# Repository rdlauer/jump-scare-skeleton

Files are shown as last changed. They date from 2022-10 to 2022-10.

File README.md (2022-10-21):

# Remotely Terrorize the Neighborhood Kids on Halloween

This IoT project uses a Notecard to build a remotely-triggered jump-scare skeleton without using a host MCU on the skeleton.

See the full project writeup [on Hackster](https://www.hackster.io/rob-lauer/remotely-terrorize-the-neighborhood-kids-on-halloween-6b9f41)!

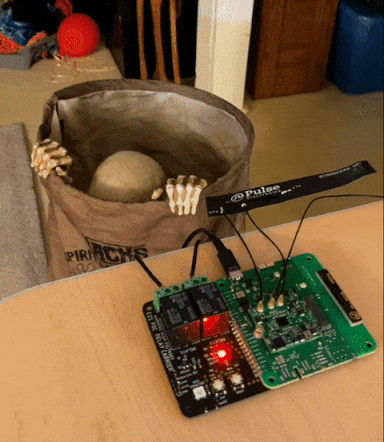
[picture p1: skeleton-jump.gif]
skeleton jump


This project uses...

- [Blues Wireless Notecard](https://blues.io/products/notecard/)
- [Blues Wireless Notecarrier-A](https://blues.io/products/notecarrier/notecarrier-a/)
- [Blues Wireless Swan](https://blues.io/products/swan/)

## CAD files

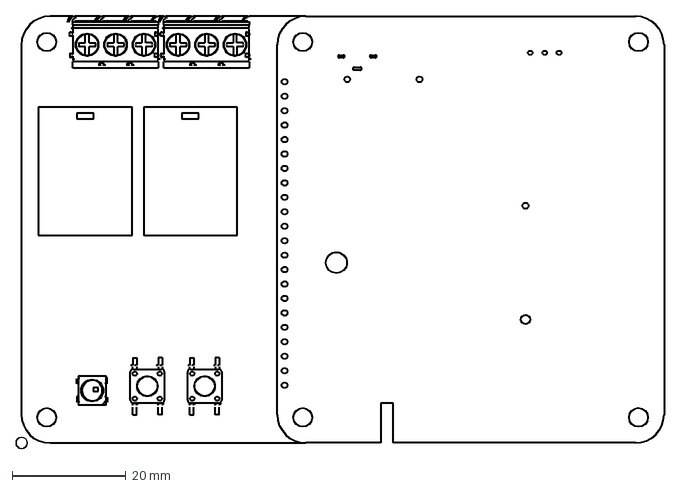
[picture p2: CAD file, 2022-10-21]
e21-relay/e21-poc/e21-design/e21-mco.dxf
113.9 x 76.0 mm

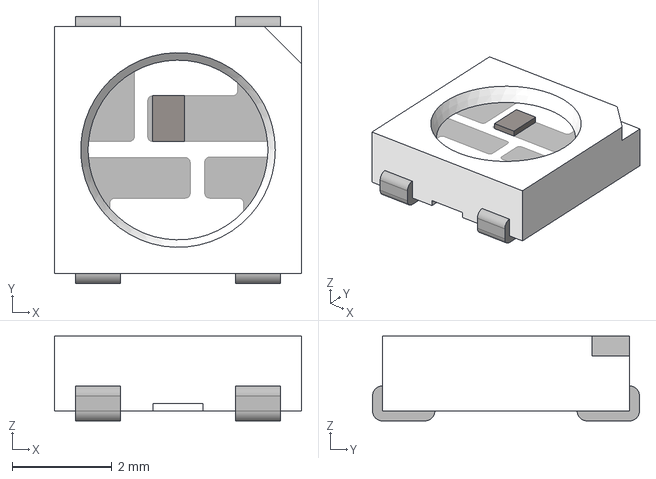
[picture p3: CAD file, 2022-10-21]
e21-relay/e21-poc/e21-design/WS2812_RGB_LED_updated.stp
4.95 x 5.35 x 1.70 mm

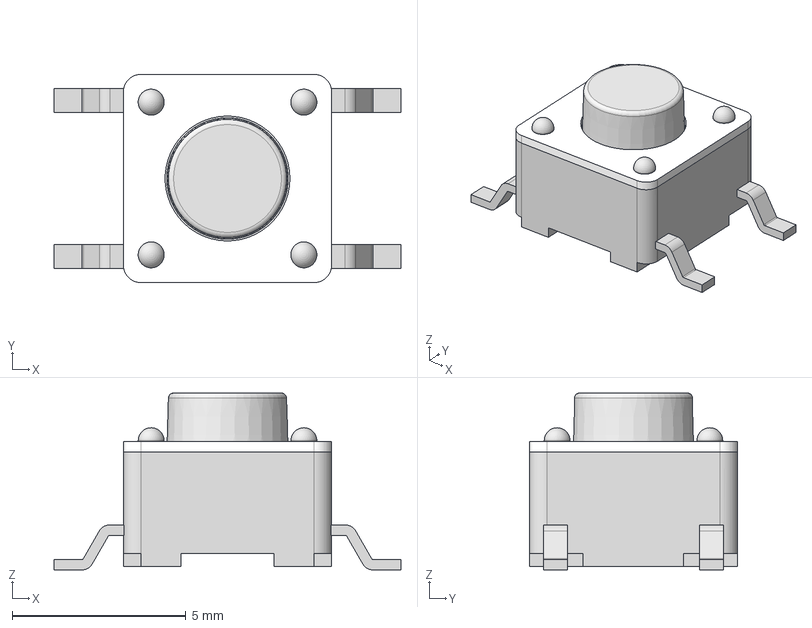
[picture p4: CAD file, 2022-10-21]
e21-relay/e21-poc/e21-design/TL3301AFxxxxG.stp
10.0 x 6.00 x 5.10 mm
TL1105CONTACTDOME
TL3301GBODY
TL1105COVER
TL1105-3301ACTUATOR A 5

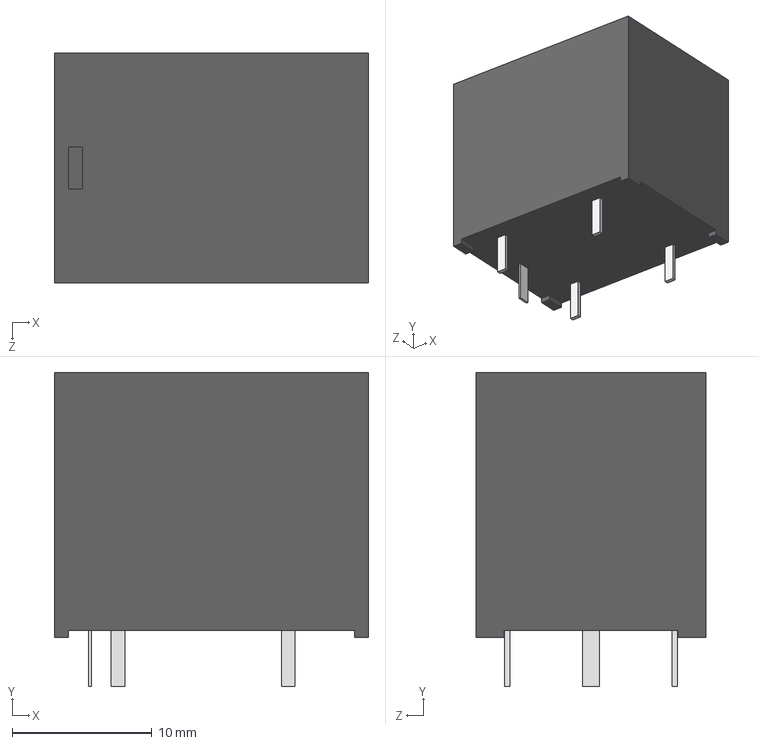
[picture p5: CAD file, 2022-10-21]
e21-relay/e21-poc/e21-design/G5LE_1.step
22.5 x 22.5 x 16.5 mm

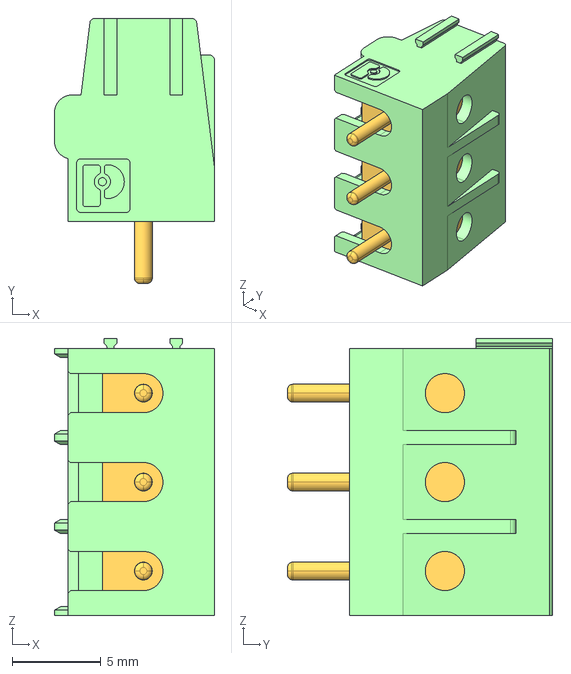
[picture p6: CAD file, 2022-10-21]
e21-relay/e21-poc/e21-design/pxc_1935174_05_PT-1-5-3-5-0-H_3D.stp
9.00 x 14.9 x 15.6 mm

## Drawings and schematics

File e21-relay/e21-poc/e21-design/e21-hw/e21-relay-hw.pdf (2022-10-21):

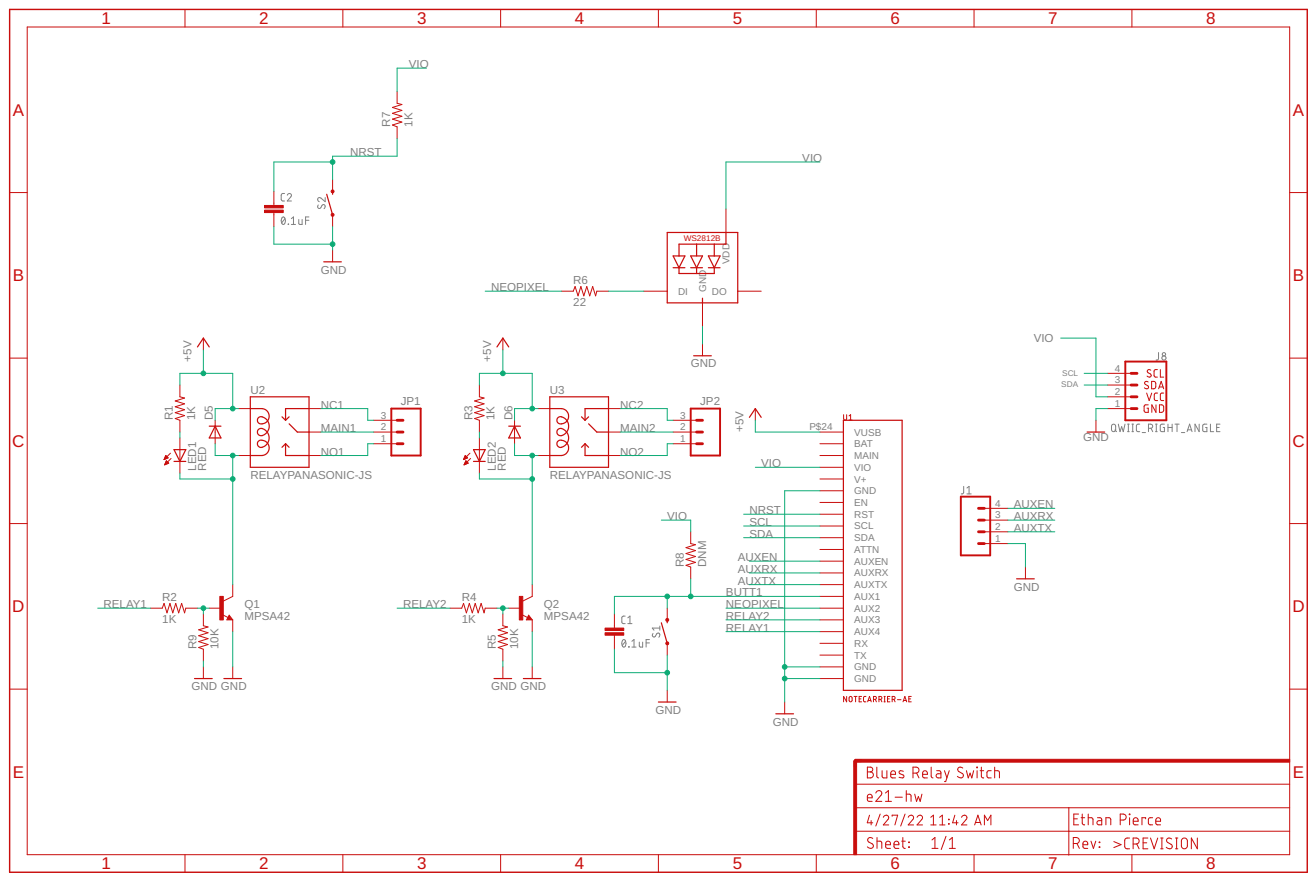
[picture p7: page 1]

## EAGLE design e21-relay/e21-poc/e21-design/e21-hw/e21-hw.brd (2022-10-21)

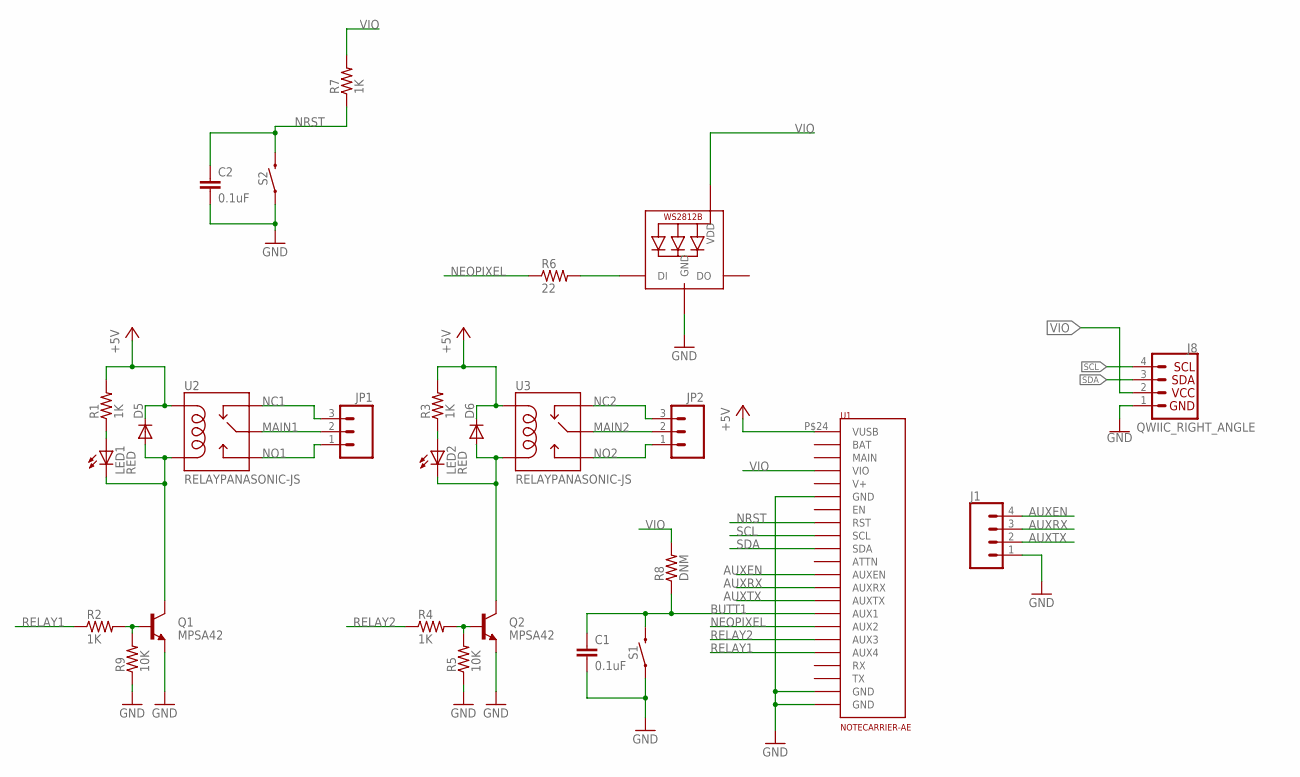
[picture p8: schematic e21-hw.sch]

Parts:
C1, C2: 0.1uF; 0603
D5, D6: DIODE-SOD123; SOD123
J1: CONN_04LOCK; 1X04_LOCK
J8: QWIIC_RIGHT_ANGLE; JST04_1MM_RA
JP1, JP2: M03-SCREW-5MM; SCREWTERMINAL-5MM-3
LED1, LED2: RED; LED-0603
LED3: WS2812B5050; WS2812B
Q1, Q2: MPSA42; SOT23
R1, R2, R3, R4, R7: 1K; 0603-RES
R5, R9: 10K; 0603-RES
R6: 22; 0603-RES
R8: DNM; 0603-RES
S1, S2: MOMENTARY-SWITCH-SPST-PTH-6.0MM; TACTILE_SWITCH_PTH_6.0MM
U1: NOTECARRIER-AE
U2, U3: RELAYPANASONIC-JS; JS1-5V-F

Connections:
+5V: D5.C, D6.C, R1.2, R3.2, U1.P$24 (VUSB), U2.COIL1, U3.COIL1
AUXEN: J1.4, U1.P$11 (AUXEN)
AUXRX: J1.3, U1.P$10 (AUXRX)
AUXTX: J1.2, U1.P$9 (AUXTX)
BUTT1: C1.1, R8.1, S1.3 (2), U1.P$8 (AUX1)
GND: C1.2, C2.2, J1.1, J8.1, LED3.3-GND (GND), Q1.2 (E), Q2.2 (E), R5.1, R9.1, S1.1, S2.1, U1.P$1 (GND), U1.P$2 (GND), U1.P$18 (GND)
MAIN1: JP1.2, U2.COMMON (MAIN)
MAIN2: JP2.2, U3.COMMON (MAIN)
unnamed: D5.A, LED1.C, Q1.3 (C), U2.COIL2
unnamed: Q2.1 (B), R4.2, R5.2
unnamed: Q1.1 (B), R2.2, R9.2
unnamed: LED1.A, R1.1
unnamed: D6.A, LED2.C, Q2.3 (C), U3.COIL2
unnamed: LED2.A, R3.1
unnamed: LED3.4-DIN (DI), R6.2
NC1: JP1.3, U2.CLOSED (NC)
NC2: JP2.3, U3.CLOSED (NC)
NEOPIXEL: R6.1, U1.P$7 (AUX2)
NO1: JP1.1, U2.OPEN (NO)
NO2: JP2.1, U3.OPEN (NO)
NRST: C2.1, R7.1, S2.3 (2), U1.P$16 (RST)
RELAY1: R2.1, U1.P$5 (AUX4)
RELAY2: R4.1, U1.P$6 (AUX3)
SCL: J8.4, U1.P$14 (SCL)
SDA: J8.3, U1.P$13 (SDA)
VIO: J8.2, LED3.1-VDD (VDD), R7.2, R8.2, U1.P$21 (VIO)

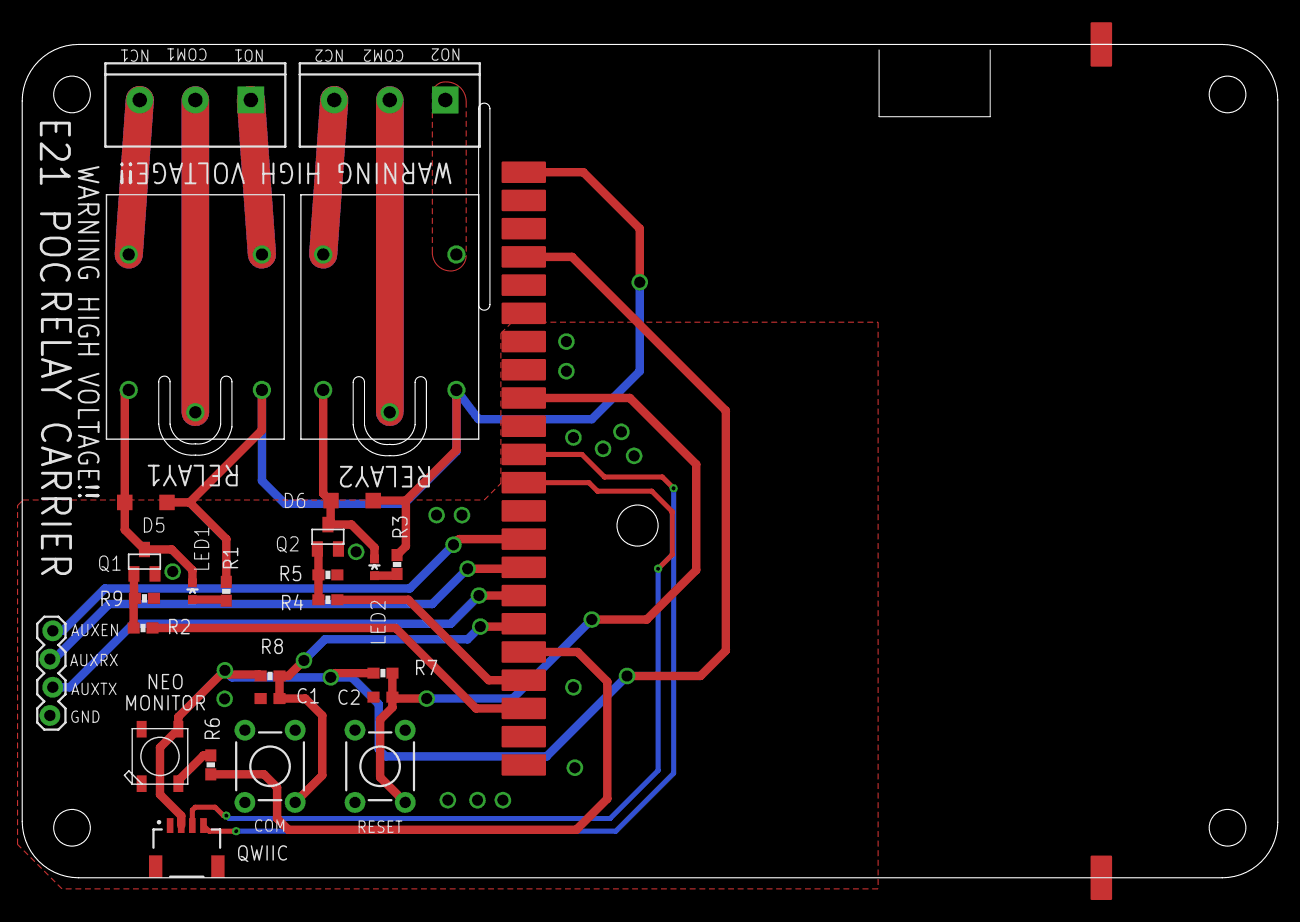
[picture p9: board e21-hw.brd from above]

Board: 2 copper layers, 113.0 x 75.0 mm, 27 parts (0 on the bottom side), 26 nets.

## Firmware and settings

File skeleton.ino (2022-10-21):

#include <Arduino.h>
#include <Wire.h>
#include <Notecard.h>

#define serialDebug Serial

const int buttonPin = 6; // the digital pin of the push button
int buttonState = 0;     // variable for reading button status

Notecard notecard;

void setup()
{
    serialDebug.begin(115200);
    while (!serialDebug)
    {
        ;
    }

    // initialize digital pin LED_BUILTIN as an output
    pinMode(LED_BUILTIN, OUTPUT);
    // initialize the push button pin as an input
    pinMode(buttonPin, INPUT);

    notecard.setDebugOutputStream(serialDebug);
    Wire.begin();
    notecard.begin();

    J *req = NoteNewRequest("hub.set");
    JAddStringToObject(req, "mode", "continuous");
    JAddStringToObject(req, "product", "<your-product-uid>");
    JAddBoolToObject(req, "sync", true);
    notecard.sendRequest(req);

    req = NoteNewRequest("hub.sync");
    notecard.sendRequest(req);
}

// the loop function runs over and over again forever
void loop()
{
    // read the state of the push button value:
    buttonState = digitalRead(buttonPin);

    // check if the push button is pressed
    if (buttonState == HIGH)
    {
        // turn LED on:
        digitalWrite(LED_BUILTIN, HIGH);

        J *req = NoteNewRequest("note.add");
        JAddStringToObject(req, "file", "surprise.qo");
        JAddBoolToObject(req, "sync", true);
        J *body = JCreateObject();
        JAddBoolToObject(body, "jump", true);
        JAddItemToObject(req, "body", body);
        notecard.sendRequest(req);

        delay(3000);
    }
    else
    {
        // turn LED off:
        digitalWrite(LED_BUILTIN, LOW);
    }
}

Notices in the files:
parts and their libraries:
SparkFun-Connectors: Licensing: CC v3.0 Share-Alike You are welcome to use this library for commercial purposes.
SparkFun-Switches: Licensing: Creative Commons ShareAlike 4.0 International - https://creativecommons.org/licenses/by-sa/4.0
